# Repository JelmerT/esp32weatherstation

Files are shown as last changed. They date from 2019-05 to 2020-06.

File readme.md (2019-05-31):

### This repository holds the firmware for a weather station based on the ESP32.

Original firmware and hardware were published in Elektor magazine: https://www.elektormagazine.com/magazine/elektor-70/42351  
Design by Roy Aarts.

The changes in this repo from the original design:  
- Removed SDS011 PM sensor and replaced by PMS5003 or [PM-E5 (hippocampus)](http://www.topsensor.cn/en/ChanPinZhanShi.html)
- Adapted project to platform.io

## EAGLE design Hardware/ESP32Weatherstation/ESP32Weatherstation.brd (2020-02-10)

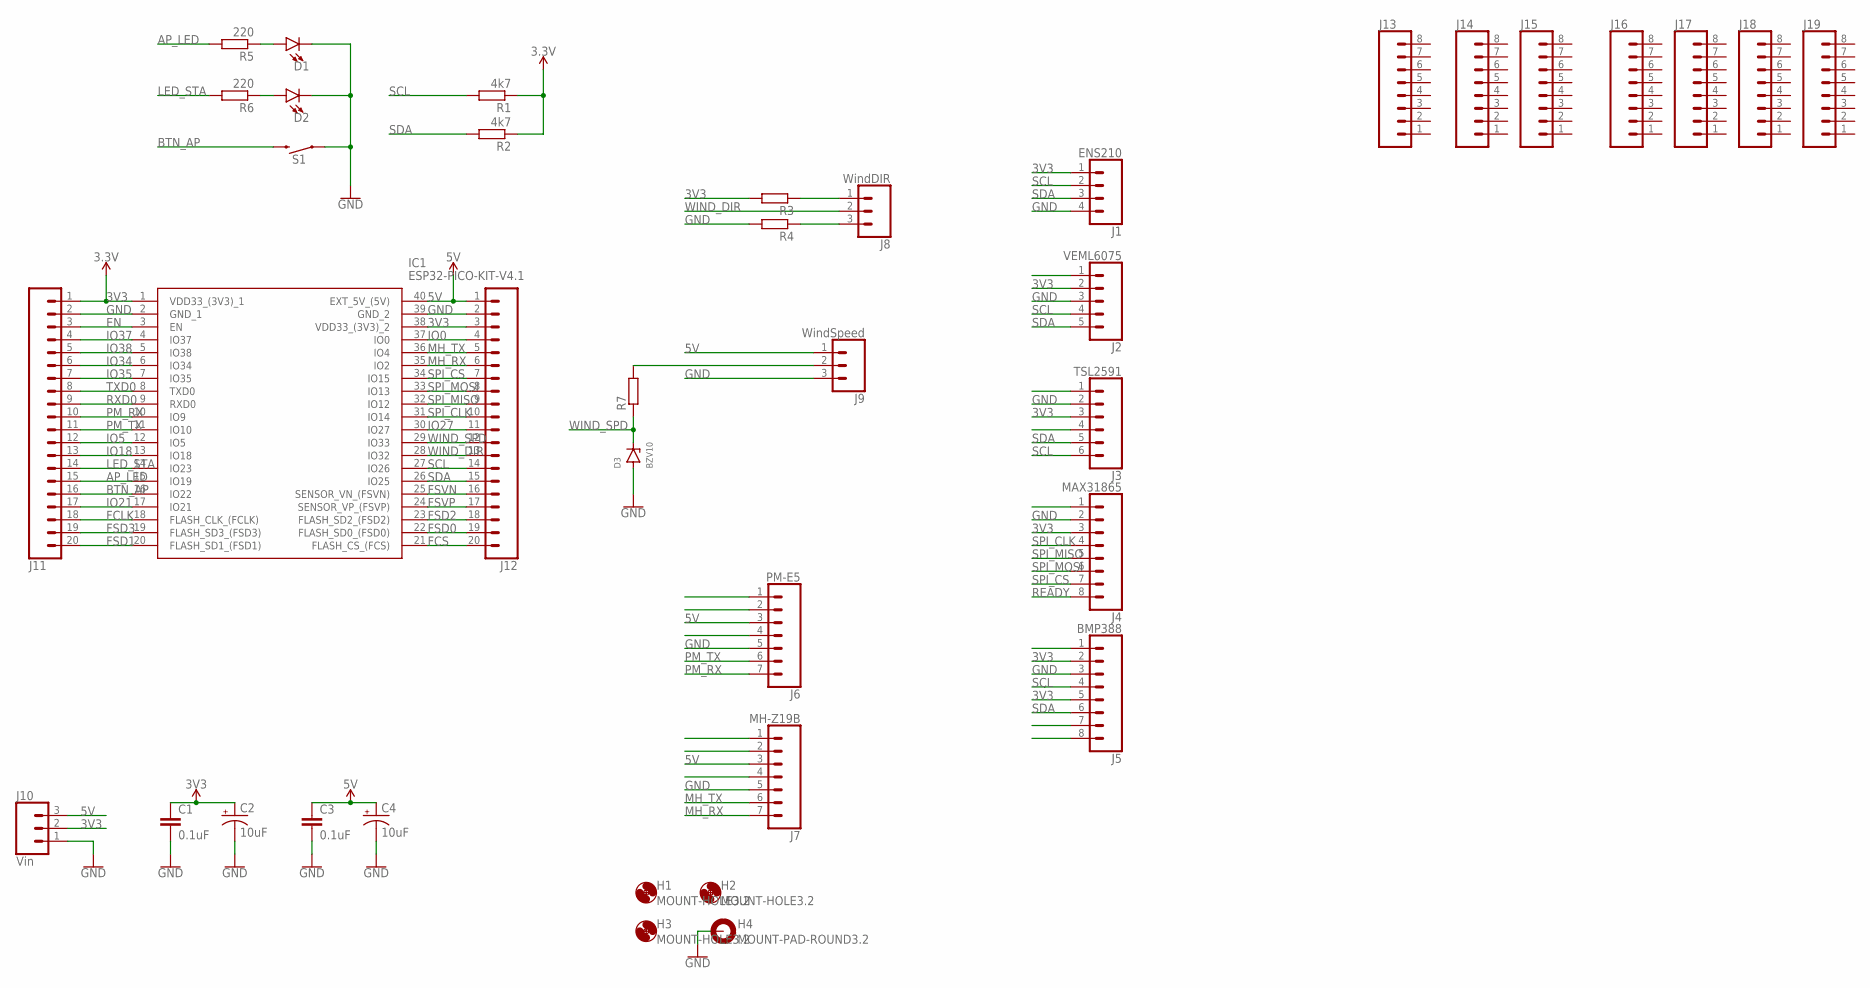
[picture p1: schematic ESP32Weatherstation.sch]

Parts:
C1, C3: 0.1uF; 0603
C2, C4: 10uF; EIA3216
D1, D2: LED3MM; LED_3MM
D3: BZV10; DO34Z7
H1, H2, H3: MOUNT-HOLE3.2; 3,2
H4: MOUNT-PAD-ROUND3.2; 3,2-PAD
IC1: ESP32-PICO-KIT-V4.1; DIPS1778W60P254L5200H1300Q40N
J1: ENS210; 1X04_NO_SILK
J2: VEML6075; 1X05_NO_SILK
J3: TSL2591; 1X06_NO_SILK
J4: MAX31865; 1X08_NO_SILK
J5: BMP388; 1X08_NO_SILK
J6: PM-E5; 1X07_NO_SILK
J7: MH-Z19B; 1X07_NO_SILK
J8: WindDIR; 1X03_NO_SILK
J9: WindSpeed; 1X03_NO_SILK
J10: Vin; 1X03_NO_SILK
J11, J12: CONN_20NOSILK; 1X20_NOSILK
J13, J14, J15, J16, J17, J18, J19: CONN_08NO_SILK_FEMALE_PTH; 1X08_NO_SILK
R1, R2: 4k7; 0207/10
R3, R4, R7: R-EU_0207/10; 0207/10
R5, R6: 220; 0207/10
S1: MOMENTARY-SWITCH-SPST-SMD-5.2MM; TACTILE_SWITCH_SMD_5.2MM

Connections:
3V3: C1.1, C2.+, IC1.1 (VDD33_(3V3)_1), IC1.38 (VDD33_(3V3)_2), J1.1, J2.2, J3.3, J4.3, J5.2, J5.5, J10.2, J11.1, J12.3, R1.1, R2.1, R3.2
5V: C3.1, C4.+, IC1.40 (EXT_5V_(5V)), J6.3, J7.3, J9.1, J10.3, J12.1
AP_LED: IC1.15 (IO19), J11.15, R5.2
BTN_AP: IC1.16 (IO22), J11.16, S1.3 (2)
EN: IC1.3 (EN), J11.3
FCLK: IC1.18 (FLASH_CLK_(FCLK)), J11.18
FCS: IC1.21 (FLASH_CS_(FCS)), J12.20
FSD0: IC1.22 (FLASH_SD0_(FSD0)), J12.19
FSD1: IC1.20 (FLASH_SD1_(FSD1)), J11.20
FSD2: IC1.23 (FLASH_SD2_(FSD2)), J12.18
FSD3: IC1.19 (FLASH_SD3_(FSD3)), J11.19
FSVN: IC1.25 (SENSOR_VN_(FSVN)), J12.16
FSVP: IC1.24 (SENSOR_VP_(FSVP)), J12.17
GND: C1.2, C2.-, C3.2, C4.-, D1.K (C), D2.K (C), D3.A, H4.B3,2, IC1.2 (GND_1), IC1.39 (GND_2), J1.4, J2.3, J3.2, J4.2, J5.3, J6.5, J7.5, J9.3, J10.1, J11.2, J12.2, R4.2, S1.1
IO0: IC1.37 (IO0), J12.4
IO5: IC1.12 (IO5), J11.12
IO18: IC1.13 (IO18), J11.13
IO21: IC1.17 (IO21), J11.17
IO27: IC1.30 (IO27), J12.11
IO34: IC1.6 (IO34), J11.6
IO35: IC1.7 (IO35), J11.7
IO37: IC1.4 (IO37), J11.4
IO38: IC1.5 (IO38), J11.5
LED_STA: IC1.14 (IO23), J11.14, R6.2
MH_RX: IC1.35 (IO2), J7.7, J12.6
MH_TX: IC1.36 (IO4), J7.6, J12.5
unnamed: J8.1, R3.1
unnamed: D1.A, R5.1
unnamed: D2.A, R6.1
unnamed: J8.3, R4.1
unnamed: J9.2, R7.2
PM_RX: IC1.10 (IO9), J6.7, J11.10
PM_TX: IC1.11 (IO10), J6.6, J11.11
READY: J4.8
RXD0: IC1.9 (RXD0), J11.9
SCL: IC1.27 (IO26), J1.2, J2.4, J3.6, J5.4, J12.14, R1.2
SDA: IC1.26 (IO25), J1.3, J2.5, J3.5, J5.6, J12.15, R2.2
SPI_CLK: IC1.31 (IO14), J4.4, J12.10
SPI_CS: IC1.34 (IO15), J4.7, J12.7
SPI_MISO: IC1.32 (IO12), J4.5, J12.9
SPI_MOSI: IC1.33 (IO13), J4.6, J12.8
TXD0: IC1.8 (TXD0), J11.8
WIND_DIR: IC1.28 (IO32), J8.2, J12.13
WIND_SPD: D3.C, IC1.29 (IO33), J12.12, R7.1

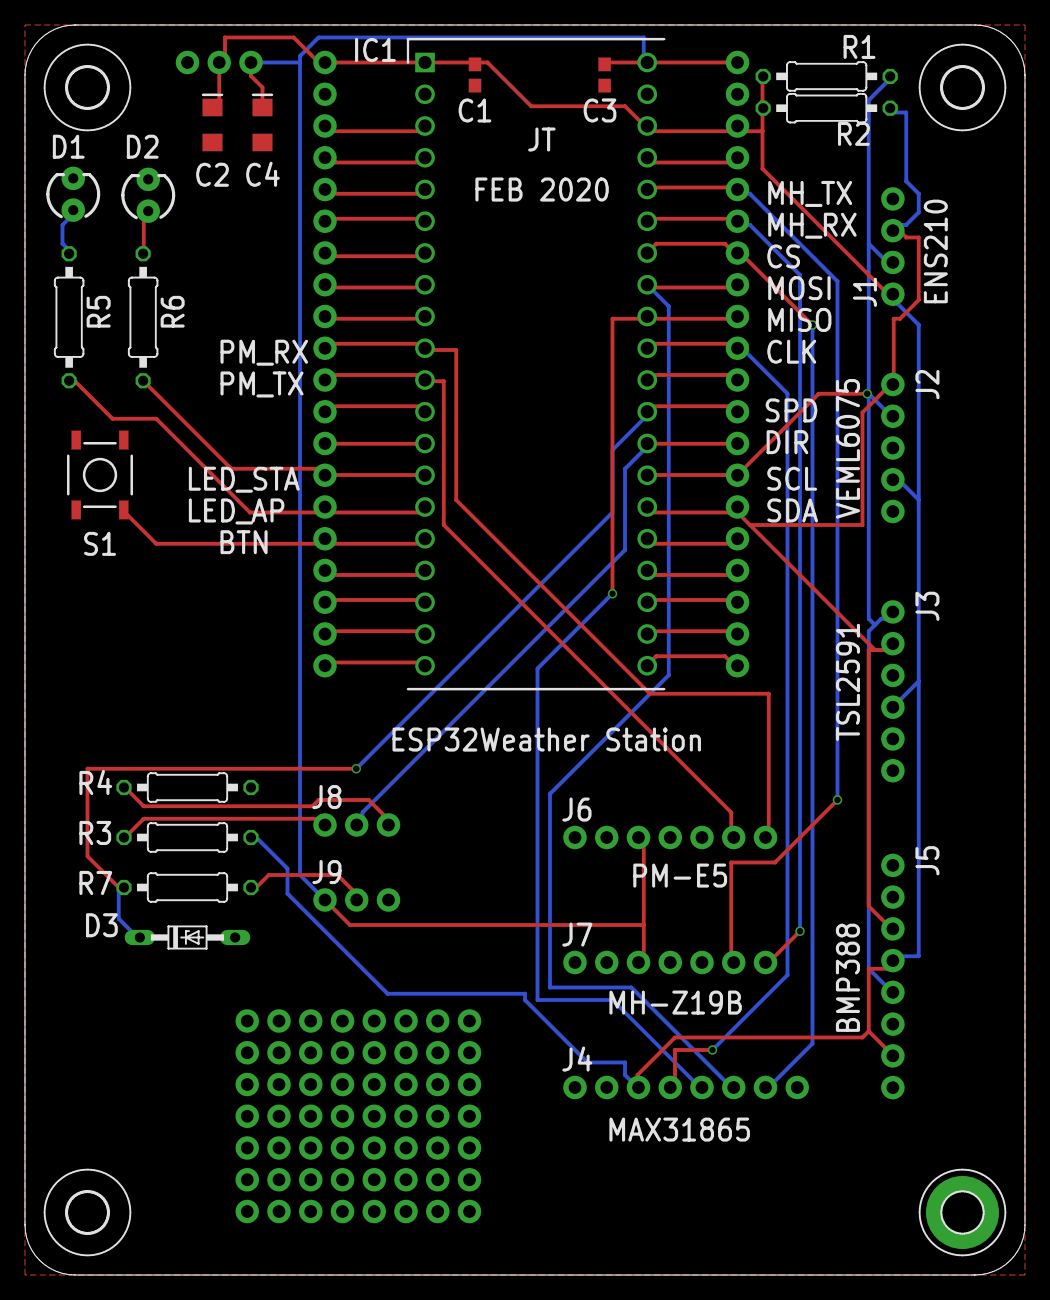
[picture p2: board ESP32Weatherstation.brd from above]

Board: 2 copper layers, 80.0 x 100.0 mm, 39 parts (0 on the bottom side), 43 nets.

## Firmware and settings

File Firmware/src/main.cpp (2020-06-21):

#include <Arduino.h>

#include <Wire.h>

#include <pms.h>
#include <Adafruit_Sensor.h>
#include "Adafruit_TSL2591.h"
#include "Adafruit_VEML6075.h"
#include "Adafruit_BMP3XX.h"
#include "ens210.h" // ENS210 library
#include <Adafruit_MAX31865.h>
#include <SoftwareSerial.h>
#include <MHZ19.h>
// rtc library
#include <RV-3028-C7.h>
#include "WeatherMeters.h"


// Pin Configs
#define APPin 22
#define APLed 19
#define STALed 23

const int windvane_pin = 32;
const int anemometer_pin = 33;
const int raingauge_pin = 27;

// Firmware configs
// The value of the Rref resistor. Use 430.0 for PT100 and 4300.0 for PT1000
#define RREF      4300.0
// The 'nominal' 0-degrees-C resistance of the sensor
// 100.0 for PT100, 1000.0 for PT1000
#define RNOMINAL  1000.0

#define SEALEVELPRESSURE_HPA 1013.25
#define RAIN_BUCKET_SIZE 0.33


// Global variables

//ENS210
float ens210_temperature = 0;
int   ens210_humidity = 0;

//VEML6075
float veml6075_UVA = 0;
float veml6075_UVB = 0;
float veml6075_UVI = 0;

//TSL2591
int tsl_lux = 0;
int tsl_ir = 0;
int tsl_full = 0;
int tsl_vis = 0;

//MAX31865
float max31865_temperature = 0;

//BMP388
float bmp_temperature = 0; //*C
float bmp_pressure = 0; //hPa
float bmp_pressureHg = 0; //mmHg
float bmp_altitude = 0;

//PMS5003
float pms5003_pm1;
float pms5003_pm2;
float pms5003_pm10;


//MH-Z19B
float mhz19_co2;
float mhz19_min_co2;
float mhz19_temperature;
float mhz19_accuracy;

// Weather lib
volatile bool got_data = false;
volatile bool timer_tick = false;
hw_timer_t * timer = NULL;
volatile SemaphoreHandle_t timerSemaphore;
portMUX_TYPE timerMux = portMUX_INITIALIZER_UNLOCKED;
WeatherMeters <6> meters(windvane_pin, 4);  // filter last 6 directions, refresh data every 4 sec

// Rain
float rainAmount = 0;
bool prevHallVal = false;

// Hall Sensor
int hall_sensor_value = 0;

//serial variables
String serialIn;
bool serialRdy = false;

// time interval variables
unsigned long sensorInterval = 4000; // in ms
unsigned long printInterval = 5000; // in ms
unsigned long lastSensorTime = 0;
unsigned long lastPrintTime = 0;

// Classes
//WindSensor ws(windSpeedPin, windDirPin);
Adafruit_TSL2591 tsl = Adafruit_TSL2591(2591); // pass in a number for the sensor identifier (for your use later)
Adafruit_VEML6075 uv = Adafruit_VEML6075();
Adafruit_BMP3XX bmp; // I2C
Adafruit_MAX31865 mx = Adafruit_MAX31865(15, 13, 12, 14); //spi_cs,spi_mosi,spi_miso,spi_clk
// Adafruit_MAX31865 mx = Adafruit_MAX31865(15); //spi_cs,spi_mosi,spi_miso,spi_clk
RV3028 rtc;

SoftwareSerial ss(4,2);
MHZ19 mhz(&ss);
ENS210 ens210;

PMS pms(Serial1);
PMS::DATA data;

/**************************************************************************/
/*
    Displays some basic information on this sensor from the unified
    sensor API sensor_t type (see Adafruit_Sensor for more information)
*/
/**************************************************************************/
void displayLuxSensorDetails(void)
{
  sensor_t sensor;
  tsl.getSensor(&sensor);
  Serial.println(F("------------------------------------"));
  Serial.print  (F("Sensor:       ")); Serial.println(sensor.name);
  Serial.print  (F("Driver Ver:   ")); Serial.println(sensor.version);
  Serial.print  (F("Unique ID:    ")); Serial.println(sensor.sensor_id);
  Serial.print  (F("Max Value:    ")); Serial.print(sensor.max_value); Serial.println(F(" lux"));
  Serial.print  (F("Min Value:    ")); Serial.print(sensor.min_value); Serial.println(F(" lux"));
  Serial.print  (F("Resolution:   ")); Serial.print(sensor.resolution, 4); Serial.println(F(" lux"));
  Serial.println(F("------------------------------------"));
  Serial.println(F(""));
  delay(500);
}

/**************************************************************************/
/*
    Configures the gain and integration time for the TSL2591
*/
/**************************************************************************/
void configureLuxSensor(void)
{
  Serial.println(F("Configuring TSL2591"));
  // You can change the gain on the fly, to adapt to brighter/dimmer light situations
  tsl.setGain(TSL2591_GAIN_LOW);    // 1x gain (bright light)
  //tsl.setGain(TSL2591_GAIN_MED);      // 25x gain
  //tsl.setGain(TSL2591_GAIN_HIGH);   // 428x gain

  // Changing the integration time gives you a longer time over which to sense light
  // longer timelines are slower, but are good in very low light situtations!
  tsl.setTiming(TSL2591_INTEGRATIONTIME_100MS);  // shortest integration time (bright light)
  // tsl.setTiming(TSL2591_INTEGRATIONTIME_200MS);
  //tsl.setTiming(TSL2591_INTEGRATIONTIME_300MS);
  // tsl.setTiming(TSL2591_INTEGRATIONTIME_400MS);
  // tsl.setTiming(TSL2591_INTEGRATIONTIME_500MS);
  // tsl.setTiming(TSL2591_INTEGRATIONTIME_600MS);  // longest integration time (dim light)

  /* Display the gain and integration time for reference sake */
  Serial.println(F("------------------------------------"));
  Serial.print  (F("Gain:         "));
  tsl2591Gain_t gain = tsl.getGain();
  switch(gain)
  {
    case TSL2591_GAIN_LOW:
      Serial.println(F("1x (Low)"));
      break;
    case TSL2591_GAIN_MED:
      Serial.println(F("25x (Medium)"));
      break;
    case TSL2591_GAIN_HIGH:
      Serial.println(F("428x (High)"));
      break;
    case TSL2591_GAIN_MAX:
      Serial.println(F("9876x (Max)"));
      break;
  }
  Serial.print  (F("Timing:       "));
  Serial.print((tsl.getTiming() + 1) * 100, DEC);
  Serial.println(F(" ms"));
  Serial.println(F("------------------------------------"));
  Serial.println(F(""));
}


/**************************************************************************/
/*
    Configures VEML6075
*/
/**************************************************************************/
void configureUvSensor(void){
  Serial.println("Configuring VEML6075");
    // Set the integration constant
  uv.setIntegrationTime(VEML6075_100MS);
  // Get the integration constant and print it!
  Serial.print("Integration time set to ");
  switch (uv.getIntegrationTime()) {
    case VEML6075_50MS: Serial.print("50"); break;
    case VEML6075_100MS: Serial.print("100"); break;
    case VEML6075_200MS: Serial.print("200"); break;
    case VEML6075_400MS: Serial.print("400"); break;
    case VEML6075_800MS: Serial.print("800"); break;
  }
  Serial.println("ms");

  // Set the high dynamic mode
  uv.setHighDynamic(true);
  // Get the mode
  if (uv.getHighDynamic()) {
    Serial.println("High dynamic reading mode");
  } else {
    Serial.println("Normal dynamic reading mode");
  }

  // Set the mode
  uv.setForcedMode(false);
  // Get the mode
  if (uv.getForcedMode()) {
    Serial.println("Forced reading mode");
  } else {
    Serial.println("Continuous reading mode");
  }

  // Set the calibration coefficients
  uv.setCoefficients(2.22, 1.33,  // veml6075_UVA_A and veml6075_UVA_B coefficients
                     2.95, 1.74,  // veml6075_UVB_C and veml6075_UVB_D coefficients
                     0.001461, 0.002591); // veml6075_UVA and veml6075_UVB responses
  // Set the calibration coefficients for PTFE window 0.7mm thick & 10mm dia.
  // uv.setCoefficients(2.22, 1.17,  // veml6075_UVA_A and veml6075_UVA_B coefficients
  //                 2.95, 1.58,  // veml6075_UVB_C and veml6075_UVB_D coefficients
  //                 0.007923, 0.008334); // veml6075_UVA and veml6075_UVB responses
}

/**************************************************************************/
/*
    Configures BMP388
*/
/**************************************************************************/
void configurePressureSensor(void){
  Serial.println("Configuring BMP388");
  // Set up oversampling and filter initialization
  bmp.setTemperatureOversampling(BMP3_OVERSAMPLING_8X);
  bmp.setPressureOversampling(BMP3_OVERSAMPLING_4X);
  bmp.setIIRFilterCoeff(BMP3_IIR_FILTER_COEFF_3);
  //bmp.setOutputDataRate(BMP3_ODR_50_HZ);
}

/**************************************************************************/
/*
    read IR and Full Spectrum at once and convert to lux
*/
/**************************************************************************/
void advancedLuxRead(void)
{
  // More advanced data read example. Read 32 bits with top 16 bits IR, bottom 16 bits full spectrum
  // That way you can do whatever math and comparisons you want!
  uint32_t lum = tsl.getFullLuminosity();
  uint16_t ir, full;
  ir = lum >> 16;
  full = lum & 0xFFFF;

  tsl_lux = tsl.calculateLux(full, ir);
  tsl_ir = ir;
  tsl_full = full;
  tsl_vis = full - ir;
}

/**************************************************************************/
/*
    read MAX31865
*/
/**************************************************************************/
void rtdTemperatureRead(void){
  uint16_t rtd = mx.readRTD();

  //Serial.print("RTD value: "); Serial.println(rtd);
  float ratio = rtd;
  ratio /= 32768;
  //Serial.print("Ratio = "); Serial.println(ratio,8);
  //Serial.print("Resistance = "); Serial.println(RREF*ratio,8);
  max31865_temperature = mx.temperature(RNOMINAL, RREF);

  // Check and print any faults
  uint8_t fault = mx.readFault();
  if (fault) {
    Serial.print("Fault 0x"); Serial.println(fault, HEX);
    if (fault & MAX31865_FAULT_HIGHTHRESH) {
      Serial.println("RTD High Threshold");
    }
    if (fault & MAX31865_FAULT_LOWTHRESH) {
      Serial.println("RTD Low Threshold");
    }
    if (fault & MAX31865_FAULT_REFINLOW) {
      Serial.println("REFIN- > 0.85 x Bias");
    }
    if (fault & MAX31865_FAULT_REFINHIGH) {
      Serial.println("REFIN- < 0.85 x Bias - FORCE- open");
    }
    if (fault & MAX31865_FAULT_RTDINLOW) {
      Serial.println("RTDIN- < 0.85 x Bias - FORCE- open");
    }
    if (fault & MAX31865_FAULT_OVUV) {
      Serial.println("Under/Over voltage");
    }
    mx.clearFault();
  }
}

/**************************************************************************/
/*
    Weather lib stuff
*/
/**************************************************************************/
void IRAM_ATTR intAnemometer() {
  meters.intAnemometer();
   digitalWrite(STALed, !digitalRead(STALed));
}

void intRaingauge() {
  meters.intRaingauge();
}

void IRAM_ATTR onTimer() {
  xSemaphoreGiveFromISR(timerSemaphore, NULL);
  // meters.timer();
  timer_tick = true;
}

void readDone(void) {
  got_data = true;
}

/**************************************************************************/
/*
    read PMS5003
*/
/**************************************************************************/
bool updatePmReads()
{
    int reads = 0;
    uint16_t min1 = 0, max1 = 0, sum1 = 0,
             min2 = 0, max2 = 0, sum2 = 0,
             min10 = 0, max10 = 0, sum10 = 0;
    for (int i = 0; i < 5; i++)
    {
        pms.requestRead();
        if (pms.read(data, 10000))
        {
            if (reads == 0)
            {
                min1 = data.PM_AE_UG_1_0;
                max1 = data.PM_AE_UG_1_0;
                sum1 = data.PM_AE_UG_1_0;
                min2 = data.PM_AE_UG_2_5;
                max2 = data.PM_AE_UG_2_5;
                sum2 = data.PM_AE_UG_2_5;
                min10 = data.PM_AE_UG_10_0;
                max10 = data.PM_AE_UG_10_0;
                sum10 = data.PM_AE_UG_10_0;
            }
            else
            {
                if (data.PM_AE_UG_1_0 < min1)
                    min1 = data.PM_AE_UG_1_0;
                if (max1 < data.PM_AE_UG_1_0)
                    max1 = data.PM_AE_UG_1_0;
                sum1 += data.PM_AE_UG_1_0;
                if (data.PM_AE_UG_2_5 < min2)
                    min2 = data.PM_AE_UG_2_5;
                if (max2 < data.PM_AE_UG_2_5)
                    max2 = data.PM_AE_UG_2_5;
                sum2 += data.PM_AE_UG_2_5;
                if (data.PM_AE_UG_10_0 < min10)
                    min10 = data.PM_AE_UG_10_0;
                if (max10 < data.PM_AE_UG_10_0)
                    max10 = data.PM_AE_UG_10_0;
                sum10 += data.PM_AE_UG_10_0;
            }
            reads++;
        }
    }
    if (reads > 2)
    {
        pms5003_pm1 = (float)(sum1 - min1 - max1) / (float)(reads - 2);
        pms5003_pm2 = (float)(sum2 - min2 - max2) / (float)(reads - 2);
        pms5003_pm10 = (float)(sum10 - min10 - max10) / (float)(reads - 2);
    }
    else
    {
        pms5003_pm1 = min1;
        pms5003_pm2 = min2;
        pms5003_pm10 = min10;
    }
    return reads > 0;
}

void printDigits(int digits){
  // utility function for digital clock display: prints preceding colon and leading 0
  Serial.print(":");
  if(digits < 10)
    Serial.print('0');
  Serial.print(digits);
}


/**************************************************************************/
/*
    Print all currently stored measurements over serial
*/
/**************************************************************************/
void printMeasurements(){
  unsigned long time = millis();
  Serial.printf("#####################################\n");
  Serial.println("Time active: " + String(time) + "ms\n " + String(time/1000/60) + " minutes\n " + String(time/1000/3600) + " Hours");
  Serial.printf("#####################################\n");
  Serial.printf("\n");

  Serial.println("Current time from RTC:");
  if (rtc.updateTime() == false) //Updates the time variables from RTC
  {
    Serial.print("RTC failed to update");
  } else {
    String currentTime = rtc.stringTimeStamp();
    Serial.println(currentTime);
    Serial.print("UNIX Time (rtc): "); Serial.println(rtc.getUNIX());
    Serial.println();
  }

  Serial.printf("ENS210\n");
  Serial.printf("ENS-T° %.2f °C\n", ens210_temperature);
  Serial.printf("Humidity %i %%RH\n", ens210_humidity);

  Serial.printf("-------------------------------------\n");
  Serial.printf("VEML6075\n");
  Serial.printf("Raw UVA: %.2f\n", veml6075_UVA);
  Serial.printf("Raw UVB: %.2f\n", veml6075_UVB);
  Serial.printf("UV Index: %.2f\n", veml6075_UVI);

  Serial.printf("-------------------------------------\n");
  Serial.printf("TSL2591\n");
  Serial.printf("IR: %i\n", tsl_ir);
  Serial.printf("Full: %i\n", tsl_full);
  Serial.printf("Visible: %i\n", tsl_vis);
  Serial.printf("Lux: %i\n", tsl_lux);

  Serial.printf("-------------------------------------\n");
  Serial.printf("MAX31865\n");
  Serial.printf("PT1000-T°: %.2f\n", max31865_temperature);

  Serial.printf("-------------------------------------\n");
  Serial.printf("BMP388\n");
  Serial.printf("BMP-T°: %.2f °C\n", bmp_temperature);
  Serial.printf("Pressure: %.2f hPa\n", bmp_pressure);
  Serial.printf("Pressure Hg: %.2f mmHg\n", bmp_pressureHg);
  Serial.printf("Approx. Altitude: %.1f m\n", bmp_altitude);

  Serial.printf("-------------------------------------\n");
  Serial.printf("PMS5003\n");
  Serial.printf("PM1.5:  "); Serial.println(pms5003_pm1);
  Serial.printf("PM2.5:  "); Serial.println(pms5003_pm2);
  Serial.printf("PM10:   "); Serial.println(pms5003_pm10);

  Serial.printf("-------------------------------------\n");
  Serial.printf("MH-Z19B\n");
  Serial.printf("CO2: %.0f ppm\n", mhz19_co2);
  //Serial.printf("Min CO2: %f\n", mhz19_min_co2);
  Serial.printf("SensorT°: %.1f\n", mhz19_temperature);
  //Serial.printf("Accuracy: %f\n", mhz19_accuracy);

  Serial.printf("-------------------------------------\n");
  if (got_data) {
    got_data = false;
    Serial.print("Wind degrees: ");
    Serial.print(meters.getDir(), 1);
    Serial.print(" Wind speed: ");
    Serial.print(meters.getSpeed(), 1);
    Serial.print("km/h, Rain: ");
    Serial.print(meters.getRain(), 4);
    Serial.println("mm");
  } else {
    Serial.printf("No weather data.\n");
  }

  Serial.printf("-------------------------------------\n");
  Serial.printf("Rain amount: %.2fmm\n", rainAmount);

  Serial.printf("##################xx#################\n");
}

/**************************************************************************/
/*
    Blink Led
*/
/**************************************************************************/

void blinkLed(int ledPin) {
  digitalWrite(ledPin, HIGH); 
  delay(1000); 
  digitalWrite(ledPin, LOW); 
  //delay(1000); 
}

/**************************************************************************/
/*
    read Hall
*/
/**************************************************************************/

bool readMagnet(){
  hall_sensor_value = hallRead();
  int trigger_value = 40;
  if (hall_sensor_value > trigger_value || hall_sensor_value < (trigger_value * -1))
    return true;

  return false;
}

/**************************************************************************/
/*
    read rain
*/
/**************************************************************************/
void readRainSensor() {
  //inverted logic
 if (!readMagnet() && prevHallVal) {
   rainAmount += RAIN_BUCKET_SIZE;
   Serial.printf("Rainbucket tipped: %.2fmm\n", rainAmount);
   blinkLed(STALed);
 }
 prevHallVal = readMagnet();
}

/**************************************************************************/
/*
    Serial terminal stuff
*/
/**************************************************************************/
void handleSerial() {
  if (serialRdy) {
    if (serialIn.indexOf("p") != -1) {
      printMeasurements();
    }
    else if (serialIn.indexOf("r") != -1) {
      ESP.restart();
    }
    else if (serialIn.indexOf("t") != -1) {
      unsigned long time = millis();
      Serial.println("Time active: " + String(time) + "ms, " + String(time/1000/60) + " minutes");
    }
    else if (serialIn.indexOf("T") != -1) {
      unsigned long pctime;
      const unsigned long DEFAULT_TIME = 1357041600; // Jan 1 2013

      serialIn.remove(0,1); // remove the T
      pctime = serialIn.toInt(); // read the unix time
      if( pctime >= DEFAULT_TIME) { // check the integer is a valid time (greater than Jan 1 2013)
        rtc.set24Hour();
        if (rtc.setUNIX(pctime) == false) {
          Serial.println("Something went wrong setting the RTC UNIX time");
        }
        if (rtc.setToCompilerTime() == false) {
          Serial.println("Something went wrong setting the RTC time to the compiler time");
        }
      }
    }

    serialRdy = false;
    serialIn = "";
  }
}

void checkSerial() {
  while (Serial.available()) {
    char in = Serial.read();
    Serial.print(in);
    serialIn += in;
    if (in == '\n'){
      serialRdy = true;
      handleSerial();
    }
  }
}
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
void loop() {
  //serial debugging
  checkSerial();

  // wake up pms
  pms.wakeUp();

  // Check rain sensor
  readRainSensor();

  // check weather sensors
  if (timer_tick){
    timer_tick = false;
    meters.timer();
  }
  //read sensors every 5 seconds
  if ((lastSensorTime + sensorInterval) < millis()) {

    // read ENS210
    int ens210_t_data, ens210_t_status, ens210_h_data, ens210_h_status;
    ens210.measure(&ens210_t_data, &ens210_t_status, &ens210_h_data, &ens210_h_status );
    ens210_temperature = ens210.toCelsius(ens210_t_data,10)/10.0;
    ens210_humidity = ens210.toPercentageH(ens210_h_data,1);

    // read VEML6075
    veml6075_UVA = uv.readUVA();
    veml6075_UVB = uv.readUVB();
    veml6075_UVI = uv.readUVI();

    // read TSL2591 sensor
    advancedLuxRead();

    // read MAX31865
    rtdTemperatureRead();

    // read bmp388
    if (! bmp.performReading()) {
      Serial.println("Failed to perform BMP388 reading");
      return;
    } else {
      bmp_temperature = bmp.temperature;
      bmp_pressure = (bmp.pressure / 100.0);
      bmp_pressureHg = (bmp.pressure / 100.0 * 0.75006);
      bmp_altitude = bmp.readAltitude(SEALEVELPRESSURE_HPA);
    }

    //read pms5003
    if (!updatePmReads())
      Serial.println("Failed to read PMS5003");

    //read MHZ19
    if (mhz.retrieveData() == MHZ19_RESULT_OK)
    {
      mhz19_co2 = mhz.getCO2();
      mhz19_min_co2 = mhz.getMinCO2();
      mhz19_temperature = mhz.getTemperature();
      mhz19_accuracy = mhz.getAccuracy();
    }
    else
    {
      Serial.print(F("MHZ19 Error"));
    }

    //read wind sensor
    // readWindSensor();

    lastSensorTime = millis();
  }

  //print readings every 10 seconds
  if ((lastPrintTime + printInterval) < millis()) {
    blinkLed(APLed);
    printMeasurements();
    lastPrintTime = millis();
  }

}

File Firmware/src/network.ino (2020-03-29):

String SSIDList(String separator = ",") {
  Serial.println("Scanning networks");
  String ssidList;
  int n = WiFi.scanNetworks();
  for (int i = 0; i < n; i++) {
    String ssid = WiFi.SSID(i);
    Serial.println(String(i) + ": " + ssid);
    if (ssidList.indexOf(ssid) != -1) {
      Serial.println("SSID already in list");
    }
    else {
      if (ssidList != "")
        ssidList += separator;
      ssidList += ssid;
    }
  }
  return ssidList;
}

//send a list of available networks to the client connected to the webserver
void getSSIDList() {
  Serial.println("SSID list requested");
  sendData(SSIDList());
}

//store the wifi settings configured on the webpage and restart the esp to connect to this network
void setWiFiSettings() {
  Serial.println("WiFi settings received");
  Serial.println(server->uri());
  ssid = server->arg("ssid");
  pass = server->arg("pass");
  String response = "Attempting to connect to '" + ssid + "'. The WiFi module restarts and tries to connect to the network.";
  sendData(response);
  Serial.println("Saving network credentials and restart.");
  storeNetworkCredentials();
  delay(1000);
  ESP.restart();
}

//send the wifi settings to the connected client of the webserver
void getWiFiSettings() {
  Serial.println("WiFi settings requested");
  String response;
  response += ssid + ",";
  response += SSIDList(";");
  sendData(response);
}

//store the upload settings configured on the webpage
void setUploadSettings() {
  Serial.println("Upload settings received");
  Serial.println(server->uri());
  thingspeakApi = server->arg("tsApi");
  tsfWindSpeed = server->arg("tsfWS").toInt();
  tsfWindDir = server->arg("tsfWD").toInt();
  tsfRainAmount = server->arg("tsfRA").toInt();
  tsfTemperature = server->arg("tsfT").toInt();
  tsfHumidity = server->arg("tsfH").toInt();
  tsfAirpressure = server->arg("tsfA").toInt();
  tsfPM1 = server->arg("tsfPM1").toInt();
  tsfPM2 = server->arg("tsfPM2").toInt();
  tsfPM10 = server->arg("tsfPM10").toInt();
  thingspeakEnabled = (server->arg("tsEnabled") == "1");
  senseBoxStationId = server->arg("sbStationId");
  senseBoxWindSId = server->arg("sbWindSId");
  senseBoxWindDId = server->arg("sbWindDId");
  senseBoxRainId = server->arg("sbRainId");
  senseBoxTempId = server->arg("sbTempId");
  senseBoxHumId = server->arg("sbHumId");
  senseBoxPressId = server->arg("sbPressId");
  senseBoxPM1Id = server->arg("sbPM1Id");
  senseBoxPM2Id = server->arg("sbPM2Id");
  senseBoxPM10Id = server->arg("sbPM10Id");
  senseBoxEnabled = (server->arg("sbEnabled") == "1");
  long recvInterval = server->arg("interval").toInt();
  uploadInterval = ((recvInterval <= 0) ? hourMs : (recvInterval * 60 * 1000)); //convert to ms (default is 1 hr)
  storeUploadSettings();
  sendData("Upload settings stored");
}

void getUploadSettings() {
  Serial.println("Upload settings requested");
  String response;
  response += thingspeakApi + ",";
  response += String(tsfWindSpeed) + ",";
  response += String(tsfWindDir) + ",";
  response += String(tsfRainAmount) + ",";
  response += String(tsfTemperature) + ",";
  response += String(tsfHumidity) + ",";
  response += String(tsfAirpressure) + ",";
  response += String(tsfPM1) + ",";
  response += String(tsfPM2) + ",";
  response += String(tsfPM10) + ",";
  response += String(thingspeakEnabled ? "1" : "0") + ",";
  response += senseBoxStationId + ",";
  response += senseBoxWindSId + ",";
  response += senseBoxWindDId + ",";
  response += senseBoxRainId + ",";
  response += senseBoxTempId + ",";
  response += senseBoxHumId + ",";
  response += senseBoxPressId + ",";
  response += senseBoxPM1Id + ",";
  response += senseBoxPM2Id + ",";
  response += senseBoxPM10Id + ",";
  response += String(senseBoxEnabled ? "1" : "0") + ",";
  response += String(uploadInterval / 1000 / 60); //convert to minutes
  sendData(response);
}

//send the weather data to the connected client of the webserver
void getWeatherData() {
  Serial.println("Weather data requested");
  String response;
  response += String(windSpeed*3.6) + ","; //km/h
  response += String(beaufort) + " (" + beaufortDesc + "),";
  response += String(windDir) + ",";
  response += String(windDirDeg) + ",";
  response += String(temperature) + ",";
  response += String(humidity) + ",";
  response += String(pressure) + ",";
  response += String(PM1) + ",";
  response += String(PM2) + ",";
  response += String(PM10);
  sendData(response);
}

//send the battery data to the connected client of the webserver
void getBatteryData() {
  Serial.println("Battery data requested");
  String response;
  // response += String(batteryVoltage) + ",";
  // response += String(batteryCharging ? "1" : "0");
  sendData(response);
}

//toggle the charging of the battery
void toggleCharging() {
  Serial.println("Toggle charging requested");
  // batteryCharging = !batteryCharging;
  // sendData("Battery charging " + String(batteryCharging ? "started" : "stopped"));
}

//restart the esp as requested on the webpage
void restart() {
  sendData("The ESP32 will restart and you will be disconnected from the '" + APSSID + "' network.");
  delay(1000);
  ESP.restart();
}

//get the content type of a filename
String getContentType(String filename) {
  if (server->hasArg("download")) return "application/octet-stream";
  else if (filename.endsWith(".htm")) return "text/html";
  else if (filename.endsWith(".html")) return "text/html";
  else if (filename.endsWith(".css")) return "text/css";
  else if (filename.endsWith(".js")) return "application/javascript";
  else if (filename.endsWith(".png")) return "image/png";
  else if (filename.endsWith(".gif")) return "image/gif";
  else if (filename.endsWith(".jpg")) return "image/jpeg";
  else if (filename.endsWith(".ico")) return "image/x-icon";
  else if (filename.endsWith(".xml")) return "text/xml";
  else if (filename.endsWith(".pdf")) return "application/x-pdf";
  else if (filename.endsWith(".zip")) return "application/x-zip";
  else if (filename.endsWith(".gz")) return "application/x-gzip";
  return "text/plain";
}

//send a file from the SPIFFS to the connected client of the webserver
void sendFile() {
  String path = server->uri();
  Serial.println("Got request for: " + path);
  if (path.endsWith("/")) path += "index.html";
  String contentType = getContentType(path);
  if (SPIFFS.exists(path)) {
    Serial.println("File " + path + " found");
    File file = SPIFFS.open(path, "r");
    server->streamFile(file, contentType);
    file.close();
  }
  else {
    Serial.println("File '" + path + "' doesn't exist");
    server->send(404, "text/plain", "The requested file doesn't exist");
  }
  
  lastAPConnection = millis();
}

//send data to the connected client of the webserver
void sendData(String data) {
  Serial.println("Sending: " + data);
  server->send(200, "text/plain", data);
  
  lastAPConnection = millis();
}
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

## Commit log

2020-02-10 updated file structure, added new sensors, added custom PCB design
    [ESP32Weatherstation.brd, ESP32Weatherstation.sch]
2020-03-29 fixed missing brackets
2020-04-12 move all prints to print function, remove some var that werent used, add seperate print interval, improve measurement function
2020-05-05 Hall sensor test
2020-05-05 add rainsensorRead via esp internal hall sensor. Remove old rainSensor external class
2020-05-05 improve rain sensor init
2020-06-18 removed arduino time lib
2020-06-18 fix weather lib implementation
    [main.cpp]
2020-06-19 add pinmode for weather lib and fix interrupts
    [main.cpp]
2020-06-21 convert weather lib to continues resistor value wind dir
2020-06-21 temp fix interrupt issue
    [main.cpp]

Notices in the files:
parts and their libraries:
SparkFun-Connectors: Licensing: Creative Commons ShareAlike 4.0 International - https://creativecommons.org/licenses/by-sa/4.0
